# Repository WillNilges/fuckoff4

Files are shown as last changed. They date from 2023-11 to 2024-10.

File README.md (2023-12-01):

# Project Sidegrade
Oh my god make it stop

<p align="center">
  FuckOff4 Prototype (hopefully)
</p>

Sidegrade is the fourth rendition of a piece of digital signage employed
at [Computer Science House](https://csh.rit.edu) to advertise events happening in
special rooms.

The project consists of two parts: The Hardware, and The Proxy.

## Hardware

The Hardware consists of an [ESP32](https://www.amazon.com/dp/B09QW6Y7KY?psc=1&ref=ppx_yo2ov_dt_b_product_details)
and a [2004 display](https://www.amazon.com/dp/B0C1G9GBRZ?psc=1&ref=ppx_yo2ov_dt_b_product_details). The ESP32 has
no headers, and the 2004 comes with an i2c adapter board. Using the provided Amazon links at time of writing it
costs about $34 to build. It will also require soldering supplies, four 90° male pin headers, some wire, and four
M3*16 machine screws.

Solder the following pins together, with the ESP32 facing away from the LCD. Leave some slack so that you can manipulate the two halves of the case later (ESP32 mounts in the back, 2004 Display mounts in the front)

| 2004 I2C Board | GND | VCC | SDA | SCL |
|---|-----|-----|-----|-----|
| ESP32 | GND | VIN | D33 | D32 |

Print the case. It shouldn't matter what filament is used.

Place the ESP32 on the pegs on the bottom case. Place the LCD on top of that and get the wires situated. Then, put the top case on and use the screws to fasten the top case, LCD, and bottom case together.

The firmware is written in Rust using tools from the excellent [esp-rs project](https://github.com/esp-rs).
It connects to a WiFi network, and periodically queries the proxy for text to display on the screen. It
is chiefly used to display events from the Google Calendar API. The first row is used to display the name of
the event, scrolling if necessary. The second row is used to display the time until the event, or the time
left in the event.

## Proxy

The Proxy is a simple webserver written in Rust using Actix Web. It serves the routes, unenecrypted, that the
Hardware checks to get event information. The location of interest (i.e. where the device is installed) is
configurable.

### Routes

**`/locations/<location>/event`**

Queries the Google Calendar API for events, then looks for the next event that is happening, parsing the response
and formatting it for the display.
Example:
```
History
In 00:15:23
```

# Development

Install Rust and follow the guide available in [The Rust on ESP Book](https://esp-rs.github.io/book/installation/index.html).

Specifically, [this page](https://esp-rs.github.io/book/installation/riscv-and-xtensa.html) is how you install for Xtensa platforms.

In the root of this project, run:
```
cargo install espup
espup install
cargo install ldproxy
cargo install espflash
```

These pages will probably be useful:
- https://github.com/esp-rs/esp-idf-hal
    - The Hardware Abstraction Layer library for ESP. Implements `embedded-hal`.
- https://github.com/esp-rs/esp-idf-svc
    - Wrappers for abstracting some of the more complex featuees of the ESP32, such as WiFi and HTTP requests.
 
# Deployment

## The Hardware

Plug in your ESP32, then run:

```
cargo run
```

If you just want to get serial output, you can do:

```
cargo espflash monitor
```

## The Proxy

Fill out the .env file. Then,

```
podman build . --tag fuckoff4-proxy
podman run --rm -e .env --name fuckoff4-proxy fuckoff4-proxy
```

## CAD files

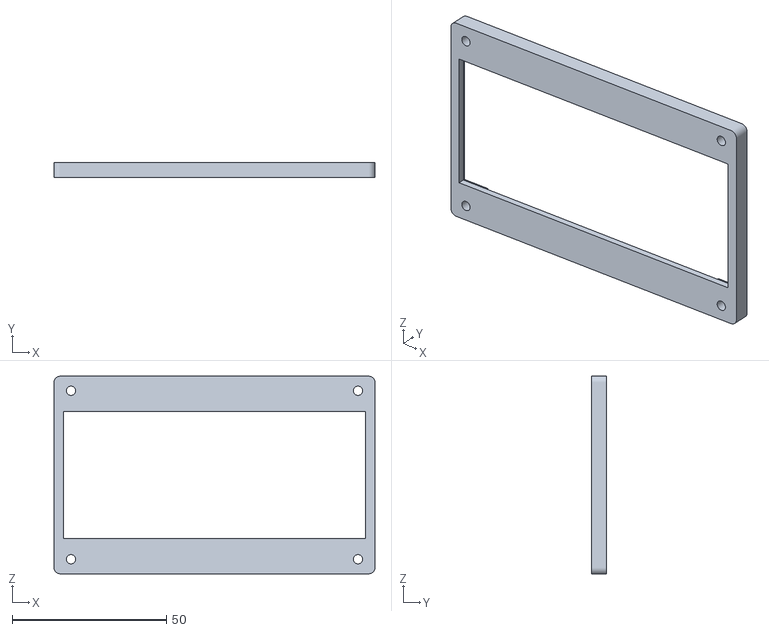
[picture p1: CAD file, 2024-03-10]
case/Sidegrade Front Case v3.stl
104.0 x 5.00 x 64.0

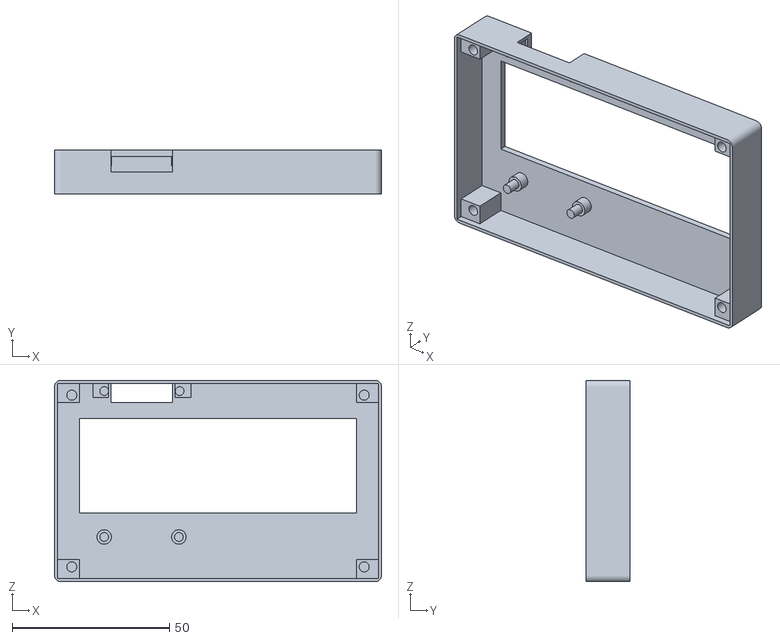
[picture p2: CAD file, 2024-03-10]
case/Sidegrade Rear Case v3.stl
104.0 x 14.0 x 64.0

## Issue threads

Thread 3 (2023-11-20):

Event_LCD Feature Pairity + Upgrades

WillNilges, 2023-11-20:
https://github.com/dag10/EventLCD/

Thou shalt not sidegrade
## `esp` firmware
- [ ] Loop to check connectivity
- [ ] Break out setup code into functions
- [ ] Create impl for display
- [ ] Option to set MAC address and other networking options
- [ ] Gracefully handle inability to connect (Update display)
- [ ] Re-try connecting to wifi
- [ ] Set backlight and other display options from server
    - [ ] Flash backlight?
- [x] Scroll title
- [ ] Display multiple events (or just the next one?)

## `proxy` software
- [ ] Reservation feature

## Hardware
- [ ] 4x20 display or better (can you find an [actual LCD](https://iotprojectsideas.com/esp32-smart-home-automation-using-dwin-hmi-display/))
- [ ] Control buttons to swap between screens?
- [ ] Thinner, Smaller footprint (requires PCB?)

WillNilges, 2023-11-20:
https://github.com/dag10/EventLCD/blob/master/website/app/views.py

WillNilges, 2023-11-21:
https://www.amazon.com/Ximimark-Display-Module-Graphic-Backlight/dp/B07T5CY8PP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

WillNilges, 2023-12-07:
https://www.makerfabs.cc/product/esp32-3-5-inch-tft-touch-camera-capacitive.html

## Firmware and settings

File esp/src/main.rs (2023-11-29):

use anyhow::bail;
use embedded_svc::{
    http::{client::Client as HttpClient, Method},
    utils::io,
    wifi::{AuthMethod, ClientConfiguration, Configuration},
};

use esp_idf_hal::{delay::FreeRtos, i2c::*, peripherals::Peripherals};

use esp_idf_svc::{
    eventloop::EspSystemEventLoop,
    http::client::EspHttpConnection,
    nvs::EspDefaultNvsPartition,
    timer::EspTaskTimerService,
    wifi::{AsyncWifi, EspWifi},
};

use hd44780_driver::bus::I2CBus;

use log::{error, info, warn};

use std::sync::{Arc, Mutex};

use futures::executor::block_on;

pub mod config;
pub mod display;

use crate::{
    config::{HZ, PASSWORD, PROXY_ROUTE, SSID},
    display::*,
};

fn main() -> anyhow::Result<()> {
    // It is necessary to call this function once. Otherwise some patches to the runtime
    // implemented by esp-idf-sys might not link properly. See https://github.com/esp-rs/esp-idf-template/issues/71
    esp_idf_svc::sys::link_patches();

    // Bind the log crate to the ESP Logging facilities
    esp_idf_svc::log::EspLogger::initialize_default();
    info!("Booting Sidegrade...");

    let peripherals = Peripherals::take()?;

    let sys_loop = EspSystemEventLoop::take()?;
    let nvs = EspDefaultNvsPartition::take()?;
    let timer_service = EspTaskTimerService::new()?;

    // Set up display
    info!("Waiting for display...");
    let i2c = peripherals.i2c1;
    let sda = peripherals.pins.gpio33;
    let scl = peripherals.pins.gpio32;
    let mut lcd = SidegradeDisplay::<I2CBus<I2cDriver>>::new_i2c(i2c, sda, scl)?;

    // Connect to Wifi
    lcd.write("Connecting...");
    info!("Setting up Wifi...");
    let mut wifi = AsyncWifi::wrap(
        EspWifi::new(peripherals.modem, sys_loop.clone(), Some(nvs))?,
        sys_loop,
        timer_service,
    )?;

    loop {
        info!("Connecting WiFi...");
        lcd.wipe();
        lcd.write("Connecting...");
        match block_on(connect_wifi(&mut wifi)) {
            Ok(()) => break,
            Err(e) => {
                warn!("Connection failed. Trying again.");
                lcd.write(format!("Can't connect.\n{}", e).as_str());
                FreeRtos::delay_ms(3000);
            }
        };
    }

    // Once we're connected, print info and start API query service, as well
    // as display service
    let ip_info = wifi.wifi().sta_netif().get_ip_info()?;
    info!("Wifi DHCP info: {:?}", ip_info);

    lcd.wipe();
    lcd.write("Query Proxy...");

    // Shared data so that the proxy thread can update the display thread
    let screen_updates = Arc::new(Mutex::new(vec![String::new(); 4]));
    let lcd_screen_updates = Arc::clone(&screen_updates);
    let query_screen_updates = Arc::clone(&screen_updates);

    /*
     * I suppose this is the bonafide main thread.
     * Nominally, it will query the proxy for a new string every HZ
     * milliseconds.
     *
     * If it fails to do so because of an issue with the server (that is, it can
     * connect to the internet, but the server doesn't respond), it will update
     * the display and set it to flash, then try to re-connect.
     */
    let proxy_thread = std::thread::Builder::new()
        .name("proxy".to_string())
        .stack_size(7000)
        .spawn(move || -> anyhow::Result<()> {
            loop {
                // GET
                let proxy_response = query_proxy();
                match proxy_response {
                    Ok(r) => {
                        info!("Proxy query successful.");
                        let mut screen = query_screen_updates.lock().unwrap();
                        *screen = r.split('\n').map(String::from).collect();
                    }
                    Err(e) => {
                        error!("Proxy Thread Error: {}", e);
                        // Spaghetti. If you see ESP_ERR_HTTP_CONNECT, then try
                        // Re-connecting to the WiFi
                        if
                        /*e.to_string() == "ESP_ERR_HTTP_CONNECT" && */
                        !wifi.is_connected()? {
                            loop {
                                info!("Connecting WiFi...");
                                {
                                    let mut screen = query_screen_updates.lock().unwrap();
                                    *screen = vec![
                                        "ESP_ERR_HTTP_CONNECT".to_string(),
                                        "Re-connecting...".to_string(),
                                        "".to_string(),
                                        "".to_string(),
                                    ];
                                }

                                match block_on(connect_wifi(&mut wifi)) {
                                    Ok(()) => break,
                                    Err(_) => {
                                        warn!("Connection failed. Trying again.");
                                        FreeRtos::delay_ms(3000);
                                    }
                                };
                            }
                        } else {
                            {
                                let mut screen = query_screen_updates.lock().unwrap();
                                *screen = vec![
                                    "Could not fetch updates.".to_string(),
                                    e.to_string(),
                                    "Check Proxy?".to_string(),
                                    "".to_string(),
                                ];
                            }
                            FreeRtos::delay_ms(3000);
                        }
                    }
                }
                FreeRtos::delay_ms(HZ);
            }
        });

    // The display thread. Basically just a billboard
    // Launched after the first attempt at querying the proxy so that the display
    // is never blank.
    let lcd_thread = std::thread::Builder::new()
        .name("display".to_string())
        .stack_size(7000)
        .spawn(move || -> anyhow::Result<()> { lcd.run(lcd_screen_updates) });

    lcd_thread?.join().unwrap()?;
    proxy_thread?.join().unwrap()?;
    info!("Joined threads");

    loop {
        // Don't let the idle task starve and trigger warnings from the watchdog.
        FreeRtos::delay_ms(100);
    }
}

async fn connect_wifi(wifi: &mut AsyncWifi<EspWifi<'static>>) -> anyhow::Result<()> {
    let wifi_configuration: Configuration = Configuration::Client(ClientConfiguration {
        ssid: SSID.into(),
        bssid: None,
        auth_method: AuthMethod::WPA2Personal,
        password: PASSWORD.into(),
        channel: None,
    });

    wifi.set_configuration(&wifi_configuration)?;

    wifi.start().await?;
    info!("Wifi started");

    wifi.connect().await?;
    info!("Wifi connected");

    wifi.wait_netif_up().await?;
    info!("Wifi netif up");

    Ok(())
}

fn query_proxy() -> anyhow::Result<String> {
    // Create HTTP(S) client
    let mut client = HttpClient::wrap(EspHttpConnection::new(&Default::default())?);
    // Prepare headers and URL
    let headers = [("accept", "text/plain")];

    // Send request
    //
    // Note: If you don't want to pass in any headers, you can also use `client.get(url, headers)`.
    let request = client.request(Method::Get, PROXY_ROUTE, &headers)?;
    info!("-> GET {}", PROXY_ROUTE);
    let mut response = request.submit()?;

    // Process response
    let status = response.status();
    info!("<- {}", status);
    let mut buf = [0u8; 1024];
    let bytes_read = io::try_read_full(&mut response, &mut buf).map_err(|e| e.0)?;
    info!("Read {} bytes", bytes_read);
    match std::str::from_utf8(&buf[0..bytes_read]) {
        Ok(body_string) => {
            info!(
                "Response body (truncated to {} bytes): {:?}",
                buf.len(),
                body_string
            );
            Ok(body_string.to_string())
        }
        Err(e) => bail!("Error decoding response body: {}", e),
    }
    // Drain the remaining response bytes
    // It's rust, this isn't necessary... right?
    //while response.read(&mut buf)? > 0 {}
}

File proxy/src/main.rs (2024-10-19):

use actix_web::{get, web, App, HttpServer, Responder};
use chrono::{DateTime, Utc};
use convert_case::{Case, Casing};
use dotenvy::dotenv;

use std::env;

use async_mutex::Mutex;

pub mod calendar;
use calendar::CalendarEvents;

struct EventCache {
    events: Mutex<CalendarEvents>,
    last_update: Mutex<DateTime<Utc>>,
}

async fn screen(cache: web::Data<EventCache>, location: web::Path<String>) -> String {
    println!("Get calendar events for {}", location);
    let mut last_update = cache.last_update.lock().await;
    let mut events = cache.events.lock().await;

    // Check if we need to update.
    let ttl: i64 = match env::var("CACHE_TTL") {
        Ok(t) => t.parse::<i64>().unwrap(),
        Err(_) => 30,
    };

    if Utc::now() > *last_update + chrono::Duration::try_seconds(ttl).unwrap() {
        print!("Refreshing cache...");
        match (*events).update().await {
            Ok(_) => {
                *last_update = Utc::now();
                println!(" done");
            }
            Err(e) => {
                let msg = format!("Failed to get calendar events: {}", e).to_string();
                println!("{}", msg);
                return msg;
            }
        };
    }

    let event_text = match (*events).get_next_at_location(&location.to_case(Case::Title)) {
        Some(e) => e.format_2004(),
        None => "No upcoming events.".to_string(),
    };

    // Lol this only works in Eastern
    let now = chrono::offset::Utc::now()
        .with_timezone(&chrono_tz::US::Eastern)
        .format("%H:%M");
    let mut time_text = format!("[{}]", now);
    time_text = format!("{: >width$}", time_text, width = 20);

    match event_text.lines().count() {
        1 => format!("{}\n\n\n{}", event_text, time_text),
        _ => format!("{}\n\n{}", event_text, time_text),
    }
}

#[get("/reserve/<location>/")]
async fn reserve(
    location: web::Path<String>,
    start: web::Path<String>,
    end: web::Path<String>,
) -> impl Responder {
    let proposed_start = DateTime::parse_from_rfc3339(&start.to_string())
        .expect("Failed to parse timestamp")
        .with_timezone(&Utc);

    let proposed_end = DateTime::parse_from_rfc3339(&end.to_string())
        .expect("Failed to parse timestamp")
        .with_timezone(&Utc);

    let upcoming_events = CalendarEvents::new().await;
    match upcoming_events {
        Ok(u) => {
            if u.is_free_at_location(&location, proposed_start, proposed_end) {
                return "Is free!";
            }
            "Reserved at that time."
        }
        _ => "Failed to get calendar events",
    }
}

async fn oh_hi() -> impl Responder {
    "Oh, hi."
}

#[actix_web::main]
async fn main() -> std::io::Result<()> {
    println!("Launching sidegrade4-proxy");
    println!("Check dotenv");
    let _ = dotenv();
    println!("Run webserver");

    let cache = web::Data::new(EventCache {
        events: Mutex::new(CalendarEvents::new().await.unwrap()),
        last_update: Mutex::new(Utc::now()),
    });

    HttpServer::new(move || {
        App::new()
            .app_data(cache.clone())
            .route("/locations/{location}/event", web::get().to(screen))
            .route("/", web::get().to(oh_hi))
    })
    .bind(("0.0.0.0", 8080))?
    .run()
    .await
}

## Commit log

2023-11-19 Can print bytes from HTTP response end my life
2023-11-19 Print time and whatever
2023-11-20 Add .env.sample
2023-11-29 i2c and a whole bunch of refactoring
    * Implement i2c for 420 (nice) display
    * Make i2c address configurable
    * Update for 2004 display
    * Scroll per-line
    * structure?
    * Almost
    * ESP ERR INVALID STATE?
    * What the fuck. That worked!?
    * Async wifi for some reason
    * I think I got it
    * Clippy
    * Re-arrange
    * QEMU emulation container (also shit's broke)
    * Async Wifi machine broke
    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
    [display.rs, main.rs]
2023-12-05 Add case files
    [Sidegrade Front Case v2.stl, Sidegrade Rear Case v2.stl]
2024-03-10 Fix time formatting (#9)
    [main.rs]
2024-03-10 Wdn/new case (#8)
    * Update case
    * fix the bottom case
    * me when I bullsquid
    * cargo fmt
    * clippy
    [Sidegrade Front Case v2.stl, Sidegrade Front Case v3.stl, Sidegrade Rear Case v2.stl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]
2024-10-18 filter out canceled events (#10)
2024-10-18 switch to dotenvy
2024-10-19 explicitly ignore dotenv failures
    [main.rs]
